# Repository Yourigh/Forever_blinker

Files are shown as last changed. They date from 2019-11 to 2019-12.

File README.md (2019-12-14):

# Forever_blinker
Electronics design that blinks a LED for months on AA battery

# Current state
Blinker esign is tested and works well. 
ATTINY variant was not verified.

# Power supply
Boost converter is used to create 3.3 V (handles about 30mA load) and has low Iq. (<20uA)

# Two options
Primary assembly option is an op-amp oscillator. Tested and working.

Another option is to use ATTINY85 and program it to do the same job. (not elaborated in this repository yet)

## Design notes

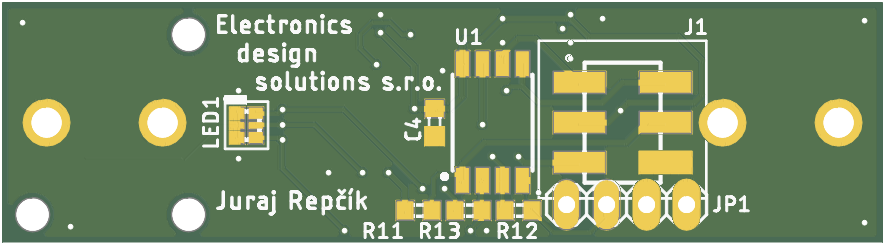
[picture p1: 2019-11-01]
CAMOutputs/CAMOutputs.png_Combined_Bottom.png

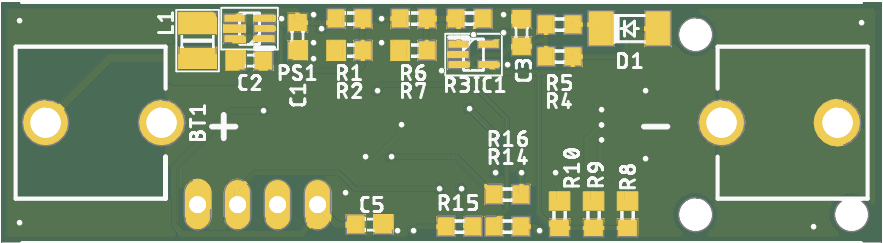
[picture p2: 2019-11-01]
CAMOutputs/CAMOutputs.png_Combined_Top.png

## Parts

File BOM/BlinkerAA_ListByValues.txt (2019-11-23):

Qty	Value	Part Num	Package	Parts
1		*	BATTERY-AA	BT1
1		*	1X04	JP1
3	0	*	R0603	R1, R12, R13
2	2.2M	*	R0603	R3, R11
2	4.7M	*	R0603	R6, R7
4	10u	GRM188R61A106KE69J	C0603K	C1, C2, C4, C5
1	12M	*	R0603	R4
1	33k	*	R0603	R5
1	100n	GRM188R61A106KE69J	C0603K	C3
1	330	*	R0603	R9
1	10129383-906001ALF	10129383-906001ALF	10129383906001ALF	J1
1	ATTINY85	*	ATTINY85	U1
1	CGRM4001-G	*	SOD-123_MINI-SMA	D1
1	CVH252009-4R7M	CVH252009-4R7M	INDC2520X100N	L1
6	DNI	*	R0603	R2, R8, R10, R14, R15, R16
1	LMV611MGX_NOPB	LMV611MGX/NOPB	SOT65P210X110-5N	IC1
1	MSL0402RGBU1	MSL0402RGBU1	MSL0402RGBU1	LED1
1	TPS61221DCKR	TPS61221DCKR	SOT65P210X110-6N	PS1

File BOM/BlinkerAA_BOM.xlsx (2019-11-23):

POWER SUPPLY AND COMMON
Qty | Value | Part Num | Package | Parts
2 |  | 534-092 | BATTERY-AA | BT1 | https://eu.mouser.com/ProductDetail/Keystone-Electronics/92
1 | CVH252009-4R7M | CVH252009-4R7M | INDC2520X100N | L1 | https://eu.mouser.com/ProductDetail/Bourns/CVH252009-4R7M
1 | TPS61221DCKR | TPS61221DCKR | SOT65P210X110-6N | PS1 | https://eu.mouser.com/ProductDetail/Texas-Instruments/TPS61221DCKR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
2 | 10u | GRM188R61A106KE69J | C0603K | C1, C2, C4, C5 | stock
1 | MSL0402RGBU1 | MSL0402RGBU1 | MSL0402RGBU1 | LED1 | stock
1 | 0 | * | R0603 | R1 | stock
1 | DNI | * | R0603 | R2 | stock
AT-TINY variant
1 |  | * | 1X04 | JP1 | stock
1 | ATTINY85 | ATTINY85-20SU | ATTINY85 | U1 | https://eu.mouser.com/ProductDetail/Microchip-Technology-Atmel/ATTINY85-20SU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
1 | 2.2M | * | R0603 | R11 | stock
2 | 10u | GRM188R61A106KE69J | C0603K | C4, C5 | stock
2 | 0 | * | R0603 | R12, R13 | stock
1 | 10129383-906001ALF | 10129383-906001ALF | 10129383906001ALF | J1 | https://eu.mouser.com/ProductDetail/Amphenol-FCI/10129383-906001ALF
3 | DNI | * | R0603 | R14, R15, R16 | stock - LED bias
OP-AMP blinker variant
1 | LMV611MGX_NOPB | LMV611MGX/NOPB or MCP6241UT-E/LT | SOT65P210X110-5N | IC1 | https://eu.mouser.com/ProductDetail/Microchip-Technology/MCP6241UT-E-LT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
1 | CGRM4001-G | * | SOD-123_MINI-SMA | D1 | https://eu.mouser.com/ProductDetail/Diodes-Incorporated/MMBD7000HS-7-F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
1 | 33k | * | R0603 | R5
1 | 12M | * | R0603 | R4
1 | 100n | GRM188R61A106KE69J | C0603K | C3
2 | 4.7M | * | R0603 | R6, R7
1 | 2.2M | * | R0603 | R3
1 | 330 | * | R0603 | R9
2 | DNI | * | R0603 | R8, R10
https://eu.mouser.com/ProjectManager/ProjectDetail.aspx?AccessID=293cc146e8

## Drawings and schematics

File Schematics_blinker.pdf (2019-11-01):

A

A

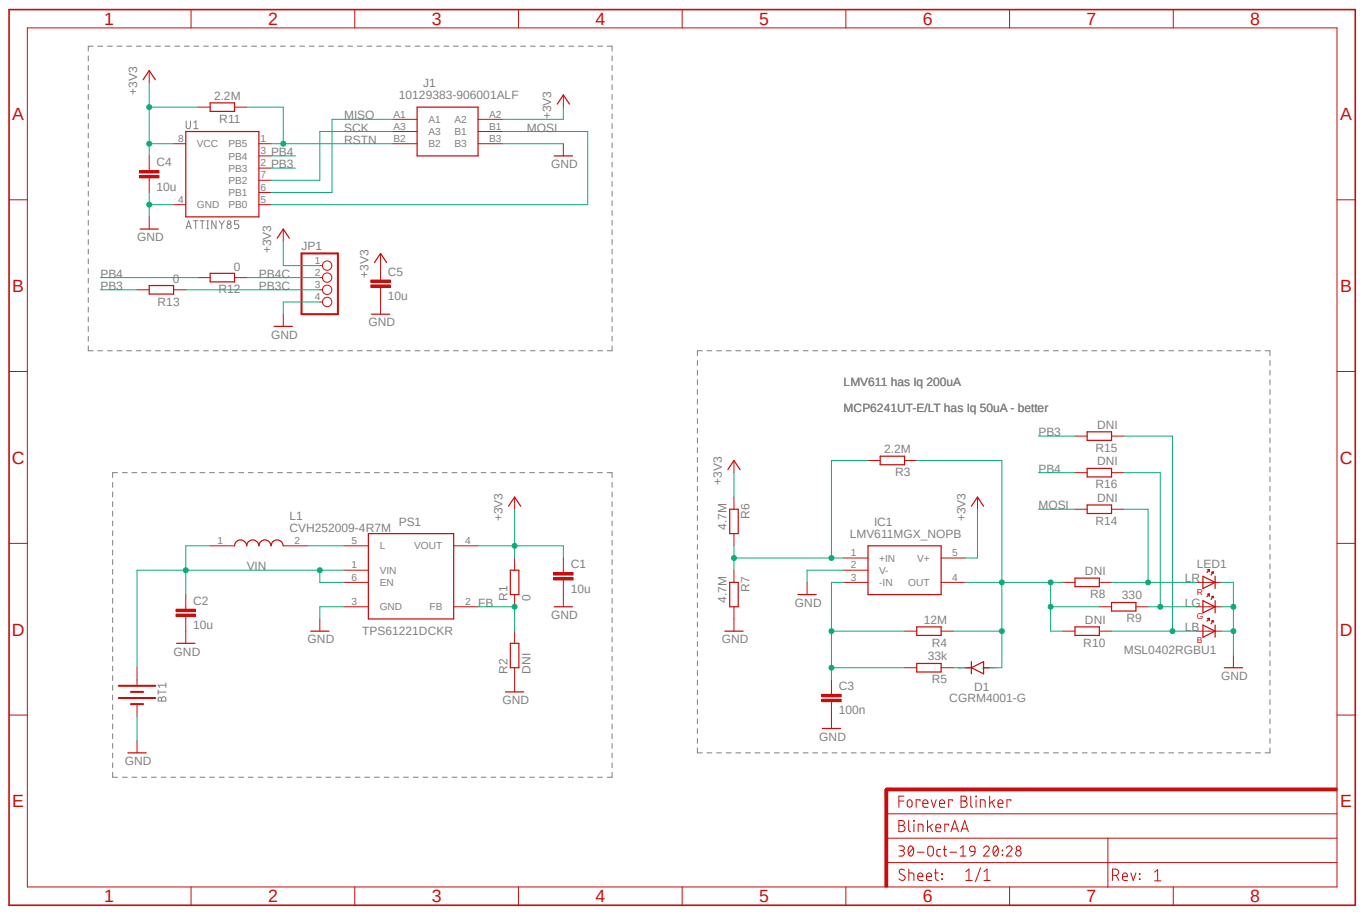
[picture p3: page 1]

LMV611 has Iq 200uA
MCP6241UT-E/LT has Iq 50uA - better

R9 DNI | G

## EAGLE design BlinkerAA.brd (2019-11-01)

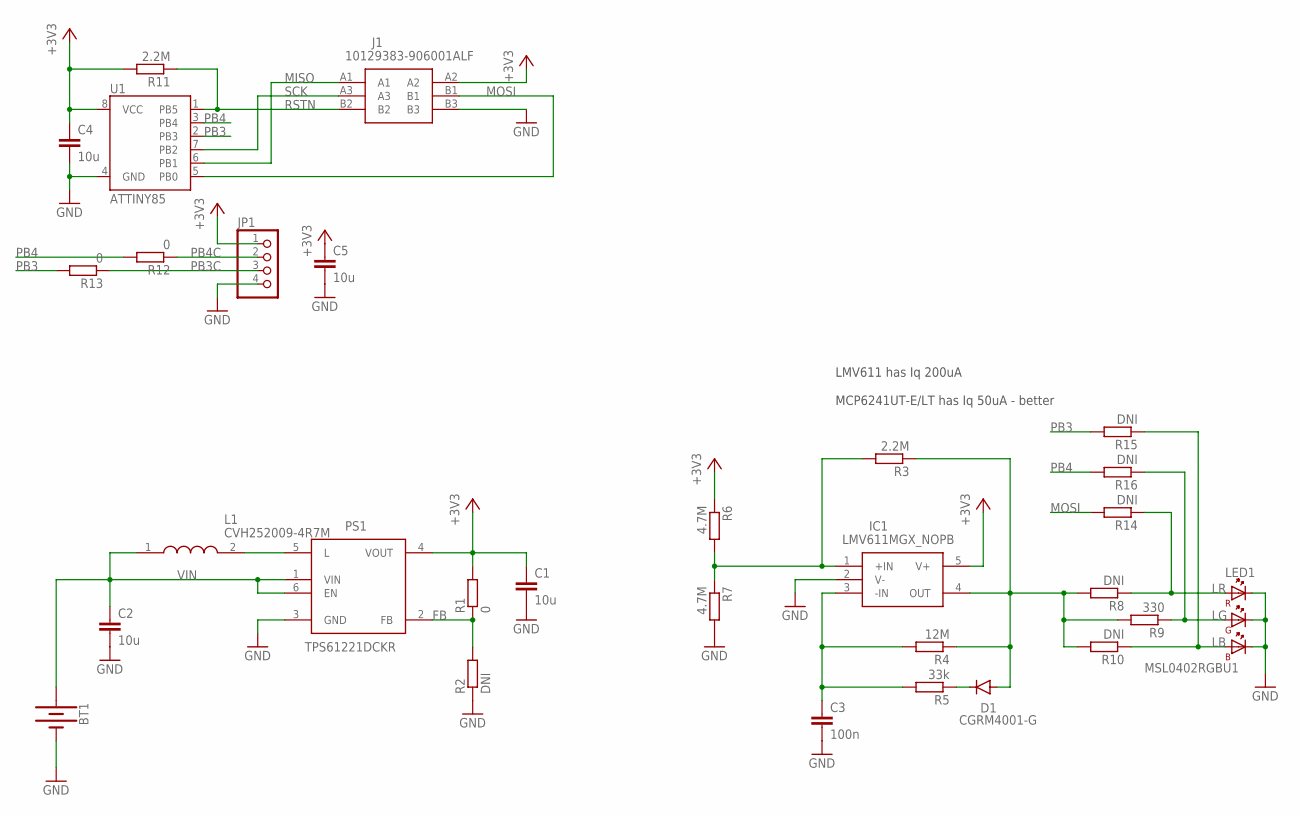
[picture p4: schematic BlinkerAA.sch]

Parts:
BT1: BATTERY-AA
C1, C2, C4, C5: 10u; C0603K; PARTNO GRM188R61A106KE69J
C3: 100n; C0603K; PARTNO GRM188R61A106KE69J
D1: CGRM4001-G; SOD-123_MINI-SMA
IC1: LMV611MGX_NOPB; SOT65P210X110-5N
J1: 10129383-906001ALF; 10129383906001ALF
JP1: PINHD-1X4; 1X04
L1: CVH252009-4R7M; INDC2520X100N
LED1: MSL0402RGBU1
PS1: TPS61221DCKR; SOT65P210X110-6N
R1, R12, R13: 0; R0603
R2, R8, R10, R14, R15, R16: DNI; R0603
R3, R11: 2.2M; R0603
R4: 12M; R0603
R5: 33k; R0603
R6, R7: 4.7M; R0603
R9: 330; R0603
U1: ATTINY85

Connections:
+3V3: C1.1, C4.1, C5.1, IC1.5 (V+), J1.A2, JP1.1, PS1.4 (VOUT), R1.2, R6.1, R11.2, U1.8 (VCC)
FB: PS1.2 (FB), R1.1, R2.2
GND: BT1.GND@1 (-), C1.2, C2.2, C3.2, C4.2, C5.2, IC1.2 (V-), J1.B3, JP1.4, LED1.1 (K_B), LED1.2 (K_G), LED1.3 (K_R), PS1.3 (GND), R2.1, R7.2, U1.4 (GND)
LB: LED1.6 (A_B), R10.1, R15.1
LG: LED1.5 (A_G), R9.1, R16.1
LR: LED1.4 (A_R), R8.1, R14.1
MISO: J1.A1, U1.6 (PB1)
MOSI: J1.B1, R14.2, U1.5 (PB0)
unnamed: IC1.1 (+IN), R3.2, R6.2, R7.1
unnamed: L1.2, PS1.5 (L)
unnamed: D1.A, IC1.4 (OUT), R3.1, R4.1, R8.2, R9.2, R10.2
unnamed: C3.1, IC1.3 (-IN), R4.2, R5.2
unnamed: D1.C, R5.1
PB3: R13.2, R15.2, U1.2 (PB3)
PB3C: JP1.3, R13.1
PB4: R12.2, R16.2, U1.3 (PB4)
PB4C: JP1.2, R12.1
RSTN: J1.B2, R11.1, U1.1 (PB5)
SCK: J1.A3, U1.7 (PB2)
VIN: BT1.PWR@1 (+), C2.1, L1.1, PS1.1 (VIN), PS1.6 (EN)

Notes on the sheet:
LMV611 has Iq 200uA MCP6241UT-E/LT has Iq 50uA - better

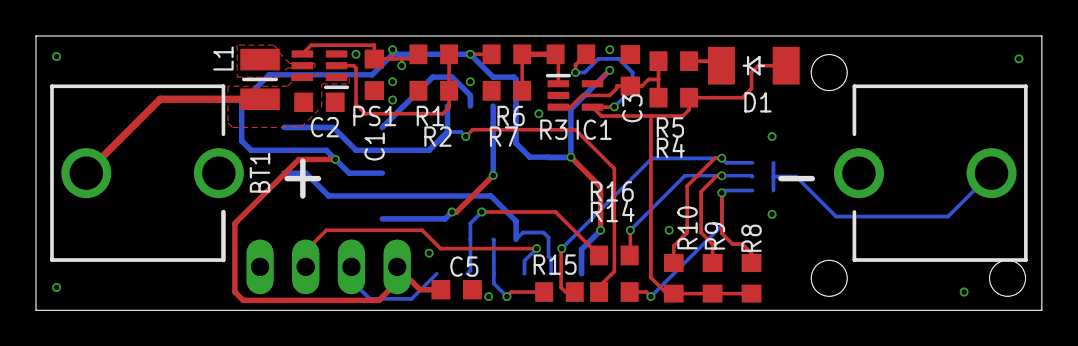
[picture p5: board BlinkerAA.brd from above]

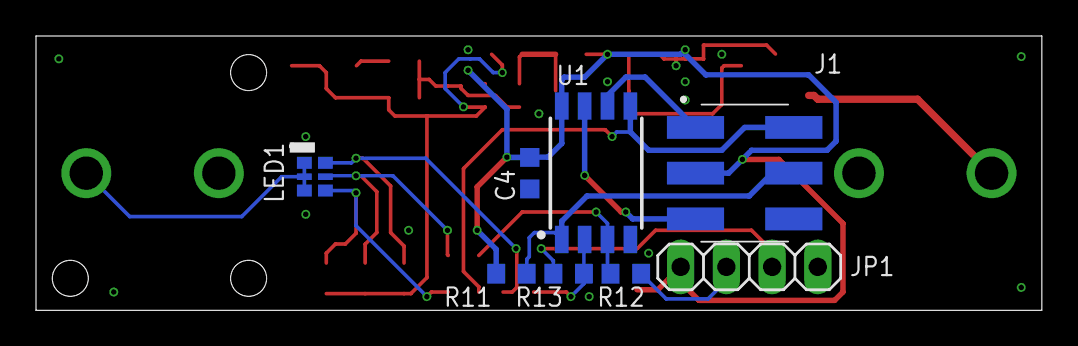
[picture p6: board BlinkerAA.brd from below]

Board: 2 copper layers, 55.9 x 15.2 mm, 30 parts (8 on the bottom side), 20 nets.

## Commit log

2019-10-29 schematics done
    [BlinkerAA.brd, BlinkerAA.sch]
2019-11-01 gerbers generation, readme update
    [BlinkerAA.brd, BlinkerAA.sch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]

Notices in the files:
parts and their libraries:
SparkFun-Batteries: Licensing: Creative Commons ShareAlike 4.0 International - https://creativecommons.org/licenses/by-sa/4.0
